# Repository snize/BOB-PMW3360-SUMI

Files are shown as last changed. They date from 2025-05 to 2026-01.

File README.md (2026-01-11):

# PMW3360 breakout board - SUMI（墨）

ブレイクアウトボード自体はBoothから購入もできます https://bulblub.booth.pm/items/6164153

## 特徴

PMW3360用のコンパクトで低コストなブレイクアウトボードです。[PMW3610 breakout board \- SEIBOKU（青墨）](https://github.com/snize/BOB-PMW3610-SEIBOKU)と同様の設計思想で設計され、自作キーボードや自作トラックボールの試作や流用・組み込みを意識しています。

- 3.3Vのみで動作に限定することで部品点数を削減し低コスト・コンパクト化
- 手はんだでの実装を前提とし手はんだ用のパッドサイズと間隔を採用
- 平面的には基板の中心とOptical Centerが一致するように配置
- 立体的にはレンズ部の厚みは約3.4mm(PMW3610は約4.0mm)で若干の違いあり

## 寸法図/Dimensions

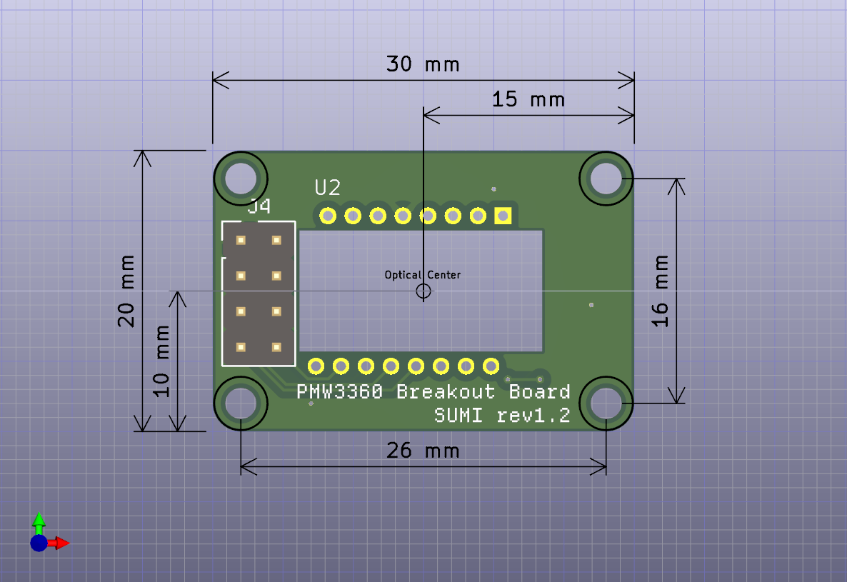
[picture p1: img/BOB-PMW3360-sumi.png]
寸法図


## 回路図/Schematic

回路図

## KiCanvasで見る

https://kicanvas.org/?github=https://github.com/snize/BOB-PMW3360-SUMI

## 部品表/BOM

| Reference | Value | Qty  |
| --- | --- | ---- |
| C1, C4 | 0.1uF | 2 |
| C2 | 1uF | 1 |
| C3 | 4.7uF/10V | 1 |
| R1, R3 | 10k | 2 |
| R2 | 39R | 1 |
| U1 | TLV70019DDCR | 1 |
| U2 | PMW3360DM-T2QU | 1 |

## 使用フォント/Font

本プロジェクトでは、**Departure Mono** フォントを使用しています。[rektdeckard/departure-mono](https://github.com/rektdeckard/departure-mono)

## ライセンス/License

This project is licensed under the CERN OHL-P v2.
You may use, distribute, and modify this design under the terms of the CERN OHL-P v2.
Original design by snize.

### 本プロジェクトを利用する場合について

- 著作権表示とライセンスの表示を残してください
- issueなどで利用した旨を報告していただけると作者が喜びます
  - 作例にバックリンクさせていただきます

## 本プロジェクトを利用した作例

DiscussionsやSNSでお知らせください！

- [HtCt44](https://github.com/snize/BOB-PMW3360-SUMI/discussions/5) by [sasadango-Jpn](https://github.com/sasadango-Jpn)
- [ortho47t](https://github.com/snize/BOB-PMW3360-SUMI/discussions/4) by [たかまる](https://x.com/Takamaru_FPV)
- [SouthernCrossTB（後付けトラックボール）](https://github.com/snize/BOB-PMW3360-SUMI/discussions/2) by [snize](https://x.com/snize)
- [Re:Square](https://github.com/snize/BOB-PMW3360-SUMI/discussions/6) by [へびたわ](https://x.com/hebino_tawagoto)

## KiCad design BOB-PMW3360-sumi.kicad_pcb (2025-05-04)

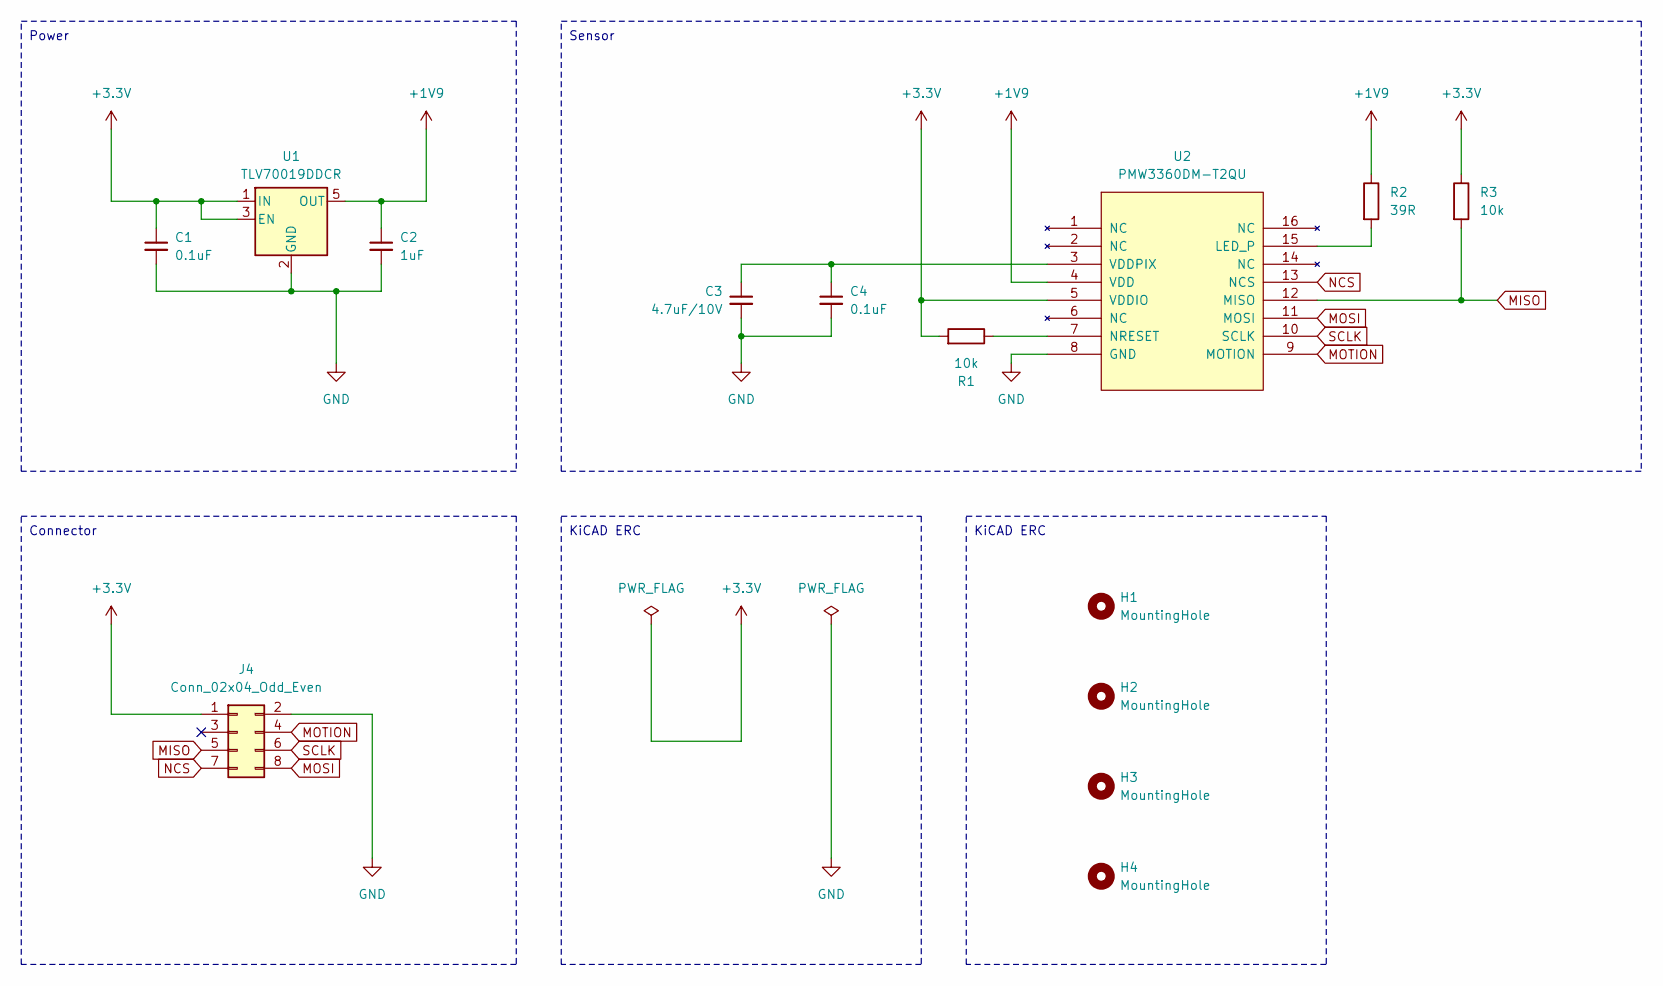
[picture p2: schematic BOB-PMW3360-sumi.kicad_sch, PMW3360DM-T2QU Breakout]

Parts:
C1, C4: 0.1uF; C_0805_2012Metric_Pad1.18x1.45mm_HandSolder
C2: 1uF; C_0805_2012Metric_Pad1.18x1.45mm_HandSolder
C3: 4.7uF/10V; C_0805_2012Metric_Pad1.18x1.45mm_HandSolder
H1, H2, H3, H4: MountingHole; MountingHole_2.2mm_M2_DIN965
J4: Conn_02x04_Odd_Even; PinHeader_2x04_P2.54mm_Vertical
R1, R3: 10k; R_0805_2012Metric_Pad1.20x1.40mm_HandSolder
R2: 39R; R_0805_2012Metric_Pad1.20x1.40mm_HandSolder
U1: TLV70019DDCR; SOT-23-5_HandSoldering
U2: PMW3360DM-T2QU

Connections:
+1V9: C2.1, R2.1, U1.5 (OUT), U2.4 (VDD)
+3.3V: C1.1, J4.1, R1.2, R3.1, U1.1 (IN), U1.3 (EN), U2.5 (VDDIO)
GND: C1.2, C2.2, C3.2, C4.2, J4.2, U1.2 (GND), U2.8 (GND)
MISO: J4.5, R3.2, U2.12 (MISO)
MOSI: J4.8, U2.11 (MOSI)
MOTION: J4.4, U2.9 (MOTION)
NCS: J4.7, U2.13 (NCS)
unnamed: R2.2, U2.15 (LED_P)
unnamed: R1.1, U2.7 (NRESET)
unnamed: C3.1, C4.1, U2.3 (VDDPIX)
SCLK: J4.6, U2.10 (SCLK)

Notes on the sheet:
Sensor
Power
KiCAD ERC
Connector

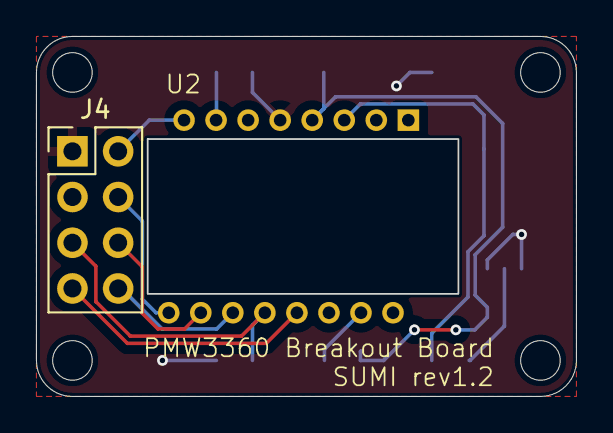
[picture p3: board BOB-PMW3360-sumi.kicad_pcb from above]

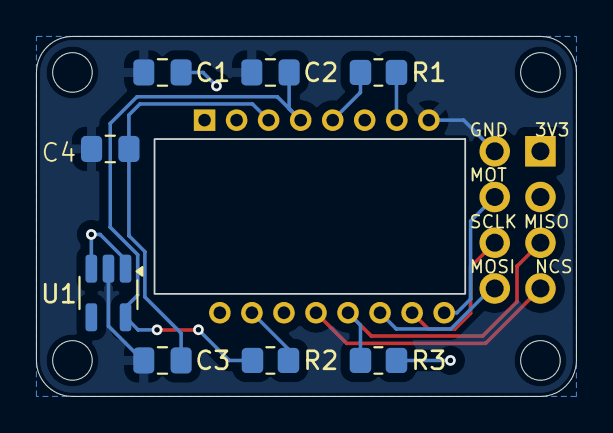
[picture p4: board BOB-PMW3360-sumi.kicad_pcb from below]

Board: 2 copper layers, 30.0 x 20.0 mm, 14 parts (8 on the bottom side), 11 nets.

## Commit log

2024-10-06 公開用最初のコミット
    [BOB-PMW3360-sumi.kicad_pcb, BOB-PMW3360-sumi.kicad_sch]
2024-10-06 寸法図を追加
    [BOB-PMW3360-sumi.kicad_pcb]
2024-12-03 設計に変更なし。ドキュメント類整理
    [BOB-PMW3360-sumi.kicad_pcb]
2024-12-03 README.mdの説明を更新
2025-01-31 Update README.md
    作例を追加
2025-05-04 シルクスクリーンとkicadのバージョンを8から9へ変更
    [BOB-PMW3360-sumi.kicad_pcb]
